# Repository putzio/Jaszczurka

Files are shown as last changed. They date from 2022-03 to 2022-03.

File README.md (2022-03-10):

# Jaszczurka

This is a project of a lizard robot, which uses 3 servomotors to move

### Program

The microcontroller we have used is AtMega 328p (the same is used in Arduino UNO).
You can find the code in "Jaszczurka" directory

### PCB
The PCB was created in Eagle and you can find it in the "Traszka" directory

### Mechanical construction
The robot was modeled in Fusion 360 and 3D printed:
https://a360.co/3q6MQ5f

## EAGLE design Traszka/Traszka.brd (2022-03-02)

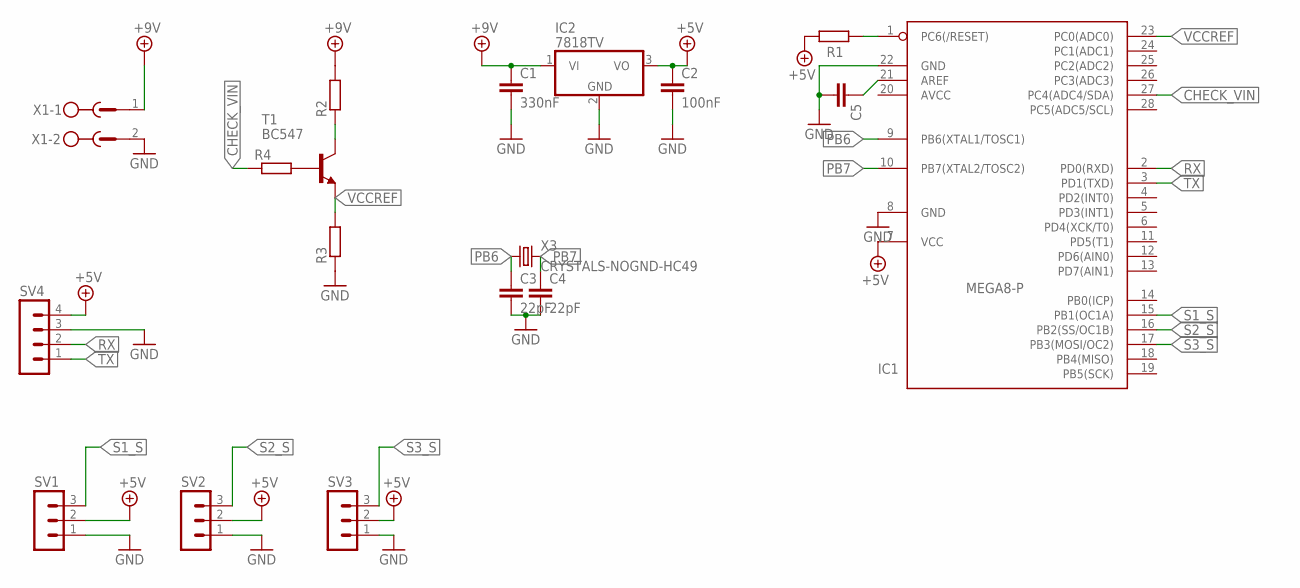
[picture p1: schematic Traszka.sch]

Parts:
C1: 330nF; C050-024X044
C2: 100nF; C050-024X044
C3, C4: 22pF; C050-024X044
C5: C-EU050-024X044; C050-024X044
IC1: MEGA8-P; DIL28-3
IC2: 7818TV; TO220V
R1, R2, R4: R-EU_0204/7; 0204/7
R3: R-EU_0204/5; 0204/5
SV1, SV2, SV3: MA03-1
SV4: MA04-1
T1: BC547; TO92
X1: MSTBV2
X3: CRYSTALS-NOGND-HC49; HC49

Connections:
+5V: C2.1, IC1.7 (VCC), IC2.3 (VO), R1.1, SV1.2, SV2.2, SV3.2, SV4.4
+9V: C1.1, IC2.1 (VI), R2.2, X1.1
AVCC: IC1.20 (AVCC)
CHECK_VIN: IC1.27 (PC4(ADC4/SDA)), R4.1
GND: C1.2, C2.2, C3.2, C4.2, C5.2, IC1.8 (GND), IC1.22 (GND), IC2.2 (GND), R3.1, SV1.1, SV2.1, SV3.1, SV4.3, X1.2
unnamed: IC1.1 (PC6(/RESET)), R1.2
unnamed: C5.1, IC1.21 (AREF)
unnamed: R2.1, T1.3 (C)
unnamed: R4.2, T1.2 (B)
PB6: C3.1, IC1.9 (PB6(XTAL1/TOSC1)), X3.1
PB7: C4.1, IC1.10 (PB7(XTAL2/TOSC2)), X3.2
RX: IC1.2 (PD0(RXD)), SV4.2
S1_S: IC1.15 (PB1(OC1A)), SV1.3
S2_S: IC1.16 (PB2(SS/OC1B)), SV2.3
S3_S: IC1.17 (PB3(MOSI/OC2)), SV3.3
TX: IC1.3 (PD1(TXD)), SV4.1
VCCREF: IC1.23 (PC0(ADC0)), R3.2, T1.1 (E)

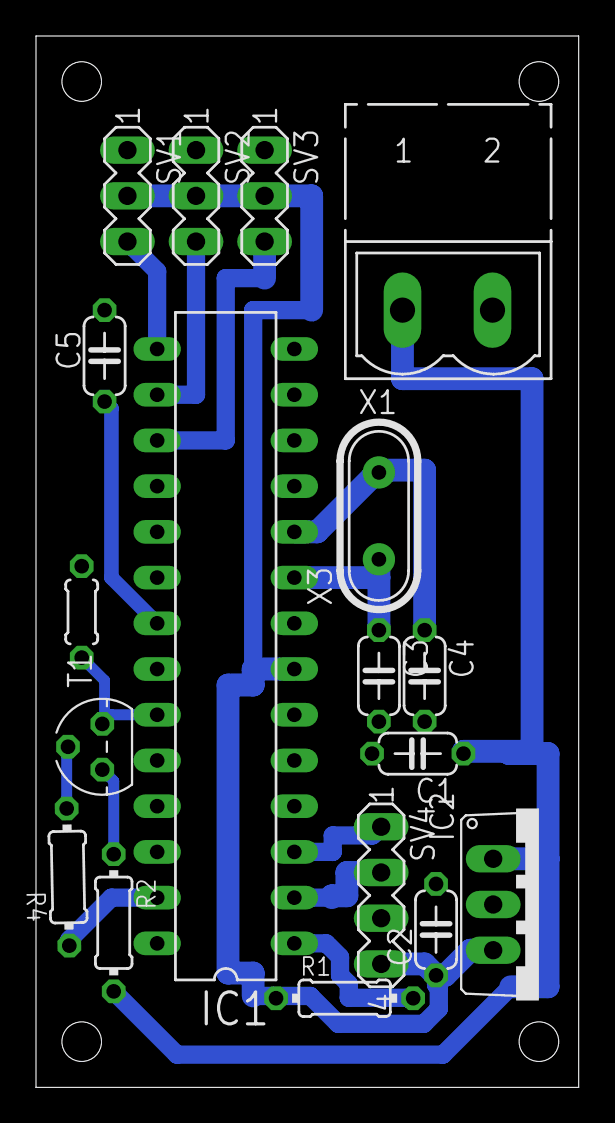
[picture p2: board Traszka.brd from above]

Board: 2 copper layers, 30.1 x 58.4 mm, 18 parts (0 on the bottom side), 16 nets.

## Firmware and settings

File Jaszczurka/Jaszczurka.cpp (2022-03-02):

#define F_CPU 16000000UL
#include <avr/io.h>
#include<util/delay.h>
#include<stdint.h>
#include<avr/interrupt.h>
#include<stdbool.h>

//do uart
#define FOSC 16000000                //czestotliwosc zegara 16MHz, bo to ten drugi, którego nie widać
#define BAUD 9600                   //szybkosc transmisji
#define MYUBRR ((FOSC)/16/BAUD)-1       //obliczenie UBRR

#define ARRAY_SIZE(a) sizeof(a)/sizeof(a[0])  //makro zwracające rozmiar tablicy
//Zmienne odbierane z modułu bt do zmiany trybu poruszania się robota:
#define  FORWARD_MESSAGE 'f'
#define  BACK_MESSAGE 'b'
#define  LEFT_MESSAGE 'l'
#define  RIGHT_MESSAGE 'r'
#define  STOP_MESSAGE 's'


//zmienne globalne
const uint8_t servo[] = {PB1,PB2,PB3};  //przód, środek, tył
volatile uint8_t pos[] ={0,90,180};     //tablica przechowująca poozycje kolejnych serw (0,1,2)
volatile uint8_t step=0;                //zmienna krok używana do znalezienia odpowiedniej instrukcji ustawienia serwo.

//tablice, w których zapisane są kolejności kroków dla poszczególnych rodzajów ruchu
const uint8_t forward []  = {0,1,2,3,4};
const uint8_t backward[]  = {0,3,2,1,4};
const uint8_t left    []  = {0,1,2,3,4,1,2,7,8};
const uint8_t right   []  = {0,3,4,1,2,3,4,5,6};

//tablica przechowująca kolejność kroków dla obecnie wykonywanego ruchu.
//Ostatnia wartość w tablicy odpowiada rozmiarowi obecnie wykonywanej tablicy instrukcji (np. dla forward m[9]=5)
uint8_t mtab    [10];

volatile char buf;               //zmienna do odbioru danych
volatile bool received = false;  //flaga do informowania o otrzymaniu nowych danych

const uint8_t leds[] = {PD2,PD3,PD4,PD5,PD6};//tablica ledów

//TIMER0
#define time 20 //ms
#define inttime FOSC*time/1000/1024 //liczba, którą normalnie wpisalibyćmy do rejestru OCR0A, jeżeli nie byłby za mały//time/1000 -> s (Hz)
#define intnumber inttime/256 //liczba wykonywanych przerwań znim zostanie urucho iona właściwa funkcja

volatile uint8_t t=0;//time

//przerwanie do odbioru danych
ISR (USART_RX_vect) {
  char rec=UDR0;//wpisanie nowych danych chara
  if(rec != buf)//sprawdzenie, czy się nie zmieniły
  {
    buf = rec;//przypisanie odebranych danych do buffera
    received=true;//Informacja do głównego programu, że przyszło coś nowego
  }
}

ISR (TIMER0_COMPA_vect) {
  t++;
}

//deklaracje funkcji:

//funkcja inicjalizująca USART
void USART_Init( unsigned int ubrr);

//funkcja inicjalizacja PWM
void PWM_Init();

//Funkcja Inicjalizująca Timer 0, który odpowiada za aktualizowanie pozycji jaszczurki
void Timer0Init();

//funkcja ustawiająca serva w żądanej pozycji
void posit (volatile uint8_t *angle);

//funkcja ustawiająca odpowiedni kąt i poruszająca servo za pomocą posit()
void move(uint8_t tab[],uint8_t size);

void ChangeMoveType(char c);//funkcja zmieniająca instrukcję do kolejnych kroków

void TurnOff();//funkcja wyłączająca ledy

void CurStep();//funkcja podająca wartość stp na diodach


int main()
{
  for(int i=0;i<ARRAY_SIZE(leds);i++)//ustawienie ledów jako wyjście
  {
    DDRD|=(1<<leds[i]);
  }
  PWM_Init();//wywolanie inicjalizacji PWM
  USART_Init ( MYUBRR );//wywolanie inicjalizacji UART
  Timer0Init();
  
  sei();//uruchomienie przerwań

  while (1)
  {
    if(t>=intnumber)
    {
      t=0;
      // CurStep();
      move (mtab,mtab[9]);//funkcja ustawiająca odpowiedni kąt i poruszająca servo za pomocą posit()
    }
    
    if(received)//jeżeli zostały odebrane dane
    {
      TurnOff();//wyłączenie diod
      ChangeMoveType(buf);
      received = false;//ustawienie flagi na false, ponieważ już zmieniliśmy dane na nowe w tabeli mtab[]
    }
  }
}

void Timer0Init()
{
  TCCR0A = (1<<WGM01);  //CTC mode
  TCCR0B = (5<<CS00);   //prescaler 1024
  OCR0A = 255;// max = 256
  TIMSK0 |= (1<<OCIE0A);
}

void USART_Init( unsigned int ubrr)
{
  /* ustawienie baud */
  UBRR0H = (unsigned char)(ubrr>>8);
  UBRR0L = (unsigned char)ubrr;
  /* odblokowanie odbiory i przerwań do jego obsługi//i transmisji */
  UCSR0B = (1<<RXEN0)|(1<<RXCIE0);//|(1<<TXEN0);
  /* Ustawienie parametrów ramki: 8data, 2stop bit */
  UCSR0C = (1<<USBS0)|(1<<UCSZ01)|(1<<UCSZ00);//(3<<UCSZ0), bo 3 to w dwójkowym 11, czyli na 1 jest UCSZ0 i UCSZ1
}

//inicjalizacja PWM
void PWM_Init(){
  //piny servo jako wyjścia
  for (int i =0;i<ARRAY_SIZE(servo);i++)
  DDRB |= (1<<servo[i]);
  
  //Fast PWM (5); Chosen output mode (non inverting)
  TCCR1A |= (1<<COM1A1)|(1<<COM1B1);
  //Waveform generation bit (fast PWM 10 bit - 1023)
  TCCR1A |= (1<<WGM10);
  TCCR1B |= (1<<WGM12);
  //PRESCALER 12MHz/1024=12kHz
  TCCR1B |= (1<<CS10) |(1<<CS12);
  
  //Dla Timera 2
  TCCR2A |= (1<<COM2A1);
  //Wybieramy Fast PWM z dużej tabeli
  TCCR2A |= (1<<WGM20)|(1<<WGM21);
  //Preskaler /1024
  TCCR2B |= ( 1<<CS22) | ( 1<<CS21) | (1<<CS20);
}

//funkcja ustawiająca serva w żądanej pozycji
void posit (volatile uint8_t *angle)
{
  int range [] = {8,38};//Zmierzone, żeby działały serwo od 0 do 180*

  if (angle[0]>=0&&angle[0]<=180)//pierwsze servo
  {
    OCR1A = angle[0]*(range[1]-range[0])/180+range[0];
  }

  if (angle[1]>=0&&angle[1]<=180)//drugie servo
  {
    OCR1B = angle[1]*(range[1]-range[0])/180 + range[0];
  }
  if (angle[2]>=0&&angle[2]<=180)//trzecie servo
  {
    OCR2A = angle[2]*(range[1]-range[0])/180+range[0];
  }
}

//funkcja ustawiająca odpowiedni kąt i poruszająca servo za pomocą posit()
void move(uint8_t tab[],uint8_t size)
{
  
  if(step+1>size)//jeżeli step wykroczył poza tablicę
  step = 1;

  switch(tab[step])//case w zależności od kroku w podanej tablicy
  {
    case 0:   //zerowanie
    {
      pos[0]=90;
      pos[1]=90;
      pos[2]=90;
      TurnOff();
      
      step++;
      break;
    }
    case 1:   //obrót środka
    {
      pos[1]++;
      if(pos[1]>=105)
      {
        step++;
      }
      PORTD |=(1<<leds[1]);
      break;
    }
    case 2:   // prawa przód, lewa tył
    {
      pos[0]++;
      pos[2]--;
      
      if(pos[2] <=60 && pos[0]>=120)
      {
        step++;
      }
      break;
    }
    case 3:   //obrót środka w drugą
    {
      TurnOff();
      pos[1]--;
      
      if(pos[1] <= 75)
      {
        step++;
      }
      break;
    }
    case 4:   // lewa przód,  prawa tył
    {
      pos[0]--;
      pos[2]++;
      
      if(pos[0] <=60 && pos[2]>=120)
      {
        step++;
      }
      break;
    }
    case 5:   //zerowanie
    {
      pos[1]--;
      if(pos[1]<=90)
      step++;
      break;
    }
    case 6:   //zerowanie nóg
    {
      pos[0]--;
      pos[2]++;
      if(pos[0]<=90&&pos[2]>=90)
      step++;
      break;
    }
    case 7:   //zerowanie
    {
      pos[1]++;
      if(pos[1]>=90)
      step++;
      break;
    }
    case 8:   //zerowanie nóg
    {
      pos[0]++;
      pos[2]--;
      if(pos[0]>=90&&pos[2]<=90)
      step++;
      break;
    }
    case 9:
    {
      _delay_ms(100);//do nothing
      break;
    }
    default:
    {
      step++;
    }
  }
  posit (pos);
}

void ChangeMoveType(char c)
{
  step = 0;
  switch (c)//przypisanie odpowiednich wartości do tabeli mtab[] w zależności od otrzymanych danych
  {
    case FORWARD_MESSAGE:
    {
      for (int i = 0;i<ARRAY_SIZE(forward);i++)
      mtab[i]=forward[i];
      mtab[9] = ARRAY_SIZE(forward);
      PORTD |=(1<<leds[1]);
      break;
    }
    case BACK_MESSAGE:
    {
      for (int i = 0;i<ARRAY_SIZE(backward);i++)
      mtab[i]=backward[i];
      mtab[9] = ARRAY_SIZE(backward);
      PORTD |=(1<<leds[2]);
      break;
    }
    case LEFT_MESSAGE:
    {
      for (int i = 0;i<ARRAY_SIZE(left);i++)
      mtab[i]=left[i];
      mtab[9] = ARRAY_SIZE(left);
      PORTD |=(1<<leds[3]);
      break;
    }
    case RIGHT_MESSAGE:
    {
      for (int i = 0;i<ARRAY_SIZE(right);i++)
      mtab[i]=right[i];
      mtab[9] = ARRAY_SIZE(right);
      PORTD |=(1<<leds[4]);
      break;
    }
    case STOP_MESSAGE:
    {
      for(int i = 0; i < ARRAY_SIZE(right); i++)
      {
        mtab[i] = 9;//all values set to 9 -> the robot will not move        
      }
    }
    default:
    {
      mtab [9] = 1;
      PORTD |=(1<<leds[0]);
    }
  }
}

void TurnOff()//funkcja wyłączająca ledy
{
  for(int i=0;i<ARRAY_SIZE(leds)-1;i++)
  PORTD&=~(1<<leds[i]);
}

void CurStep()//funkcja podająca wartość stp na diodach
{
  TurnOff();
  PORTD |= (step<<2);
}

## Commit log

2021-02-23 Elektronika v1
    [Traszka.sch]
2021-03-09 brd and UART Test
    [Traszka.brd]
2021-03-13 UART is working, F Changed from 12Mhz to 16MHz
2021-03-14 UART receve interrupt
2021-03-15 C'mon, I know why we use 16MHz oscillator
    [Jaszczurka.cpp]
2021-03-20 the move function is using timer instead of delay
2021-04-13 Final version
    [Traszka.sch]
2021-05-11 Excel file to choose the right resistors
    [Dobranie rezystorów do dzielnika z baterią.xlsx]
2022-03-02 fixing .sch and .brd checking battery
    [Traszka.brd, Traszka.sch]
